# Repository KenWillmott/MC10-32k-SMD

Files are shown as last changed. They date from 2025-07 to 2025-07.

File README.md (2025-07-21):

MC10-32k-SMD

For more details, consult the wiki: https://github.com/KenWillmott/MC10-32k-SMD/wiki

A 32k memory upgrade PCB for the Radio Shack MC-10 microcomputer. It replaces the two 2kb RAM chips and the bodged 74LS32 in the MC-10. The minimal install gives you contiguous memory from 0x0000 to 0x7FFF (except for the CPU registers in low memory). So stock Micro Color Basic recognizes and uses the the upper 16k of that, and the lower half is available for general or machine language use. There are two options:
1. Page select inputs: board inputs L0 and L1 can be connected to any digital outputs, then they will select one of four video page addresses as follows:
   mc10-modes-latch
2. Battery backup: when U4 DS1210 is installed, and 3.0V is provided at the EXT BATT terminals, the memory becomes non-volatile (contents remain while main power is removed)

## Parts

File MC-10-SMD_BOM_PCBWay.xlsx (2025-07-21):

 |  |  | xxxx xxxx xxxxx xxPCS BOM (Sample Bill of Materials)
Item # | *Designator | *Qty | Manufacturer | *Mfg Part # | Description / Value | *Package/Footprint | Type | Your Instructions / Notes
1 | U2 | 1 |  | 74HCT157 | SOP-16_3.9x9.9mm_P1.27mm | SOP-16_3.9x9.9mm_P1.27mm | SMD
2 | JP2,JP1 | 2 |  |  | SolderJumper-2_P1.3mm_Open_RoundedPad1.0x1.5mm | SolderJumper-2_P1.3mm_Open_RoundedPad1.0x1.5mm | DNS | [DNP不要贴];
3 | J4,J3 | 2 |  |  | PinHeader_1x12_P2.54mm_Vertical | PinHeader_1x12_P2.54mm_Vertical | SMD | [DNP不要贴];
4 | U3 | 1 |  | KM62256CLP | SOP-28_8.4x18.16mm_P1.27mm | SOP-28_8.4x18.16mm_P1.27mm | SMD
5 | C4,C3,C1,C2 | 4 |  | CC0603KRX7R6BB104 | 100n | C_0603_1608Metric | SMD
6 | J1 | 1 |  |  | PinHeader_1x09_P2.54mm_Vertical | PinHeader_1x09_P2.54mm_Vertical | SMD | [DNP不要贴];
7 | U4 | 1 |  | DS1210S-ND | SOIC-16W_7.5x10.3mm_P1.27mm | SOIC-16W_7.5x10.3mm_P1.27mm | SMD
8 | R2,R1 | 2 |  | RC0603FR-0710KL | 10k | R_0603_1608Metric | SMD
9 | J5 | 1 |  | Conn_01x02_Pin | PinHeader_1x02_P2.54mm_Vertical | PinHeader_1x02_P2.54mm_Vertical | SMD | [DNP不要贴];
10 | BT1 | 1 |  | BatteryHolder_Keystone_500 | BatteryHolder_Keystone_500 | BatteryHolder_Keystone_500 | DNS
11 | U1 | 1 |  | 74HCT00 | SO-14_3.9x8.65mm_P1.27mm | SO-14_3.9x8.65mm_P1.27mm | SMD
Need a quick and accurante quote? Need an efficient production? Please read SMT Ordering Necessary Files & Info in 1 minute. Thank you very much! (https://www.pcbway.com/smt_ordering_guide.html)
Click for Instructions on How to Create a BOM (https://www.pcbway.com/blog/PCB_Assembly/How_to_Build_a_BOM__Bill_Of_Materials_.html)

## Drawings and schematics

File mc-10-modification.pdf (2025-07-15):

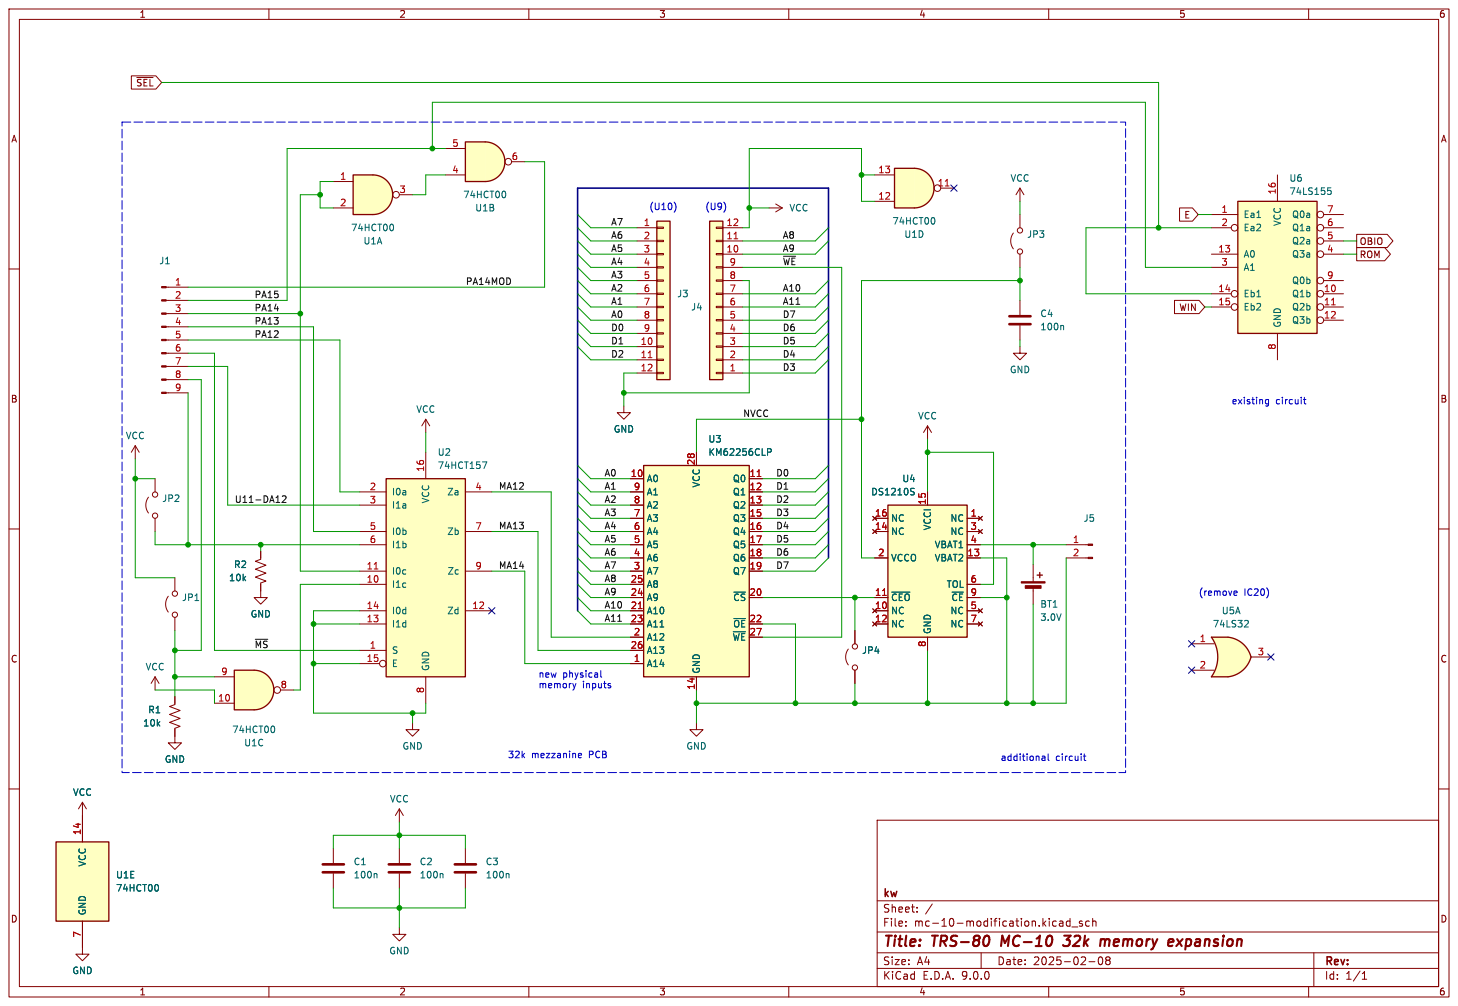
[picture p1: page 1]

8 NC 16 NC 14 VCCO 2 ~{CEO} 11 NC 10 NC 12 U4 DS1210S C2

8 NC 16 NC 14 VCCO 2 ~{CEO} 11 NC 10 NC 12

File: mc-10-modification.kicad_sch Sheet: / kw

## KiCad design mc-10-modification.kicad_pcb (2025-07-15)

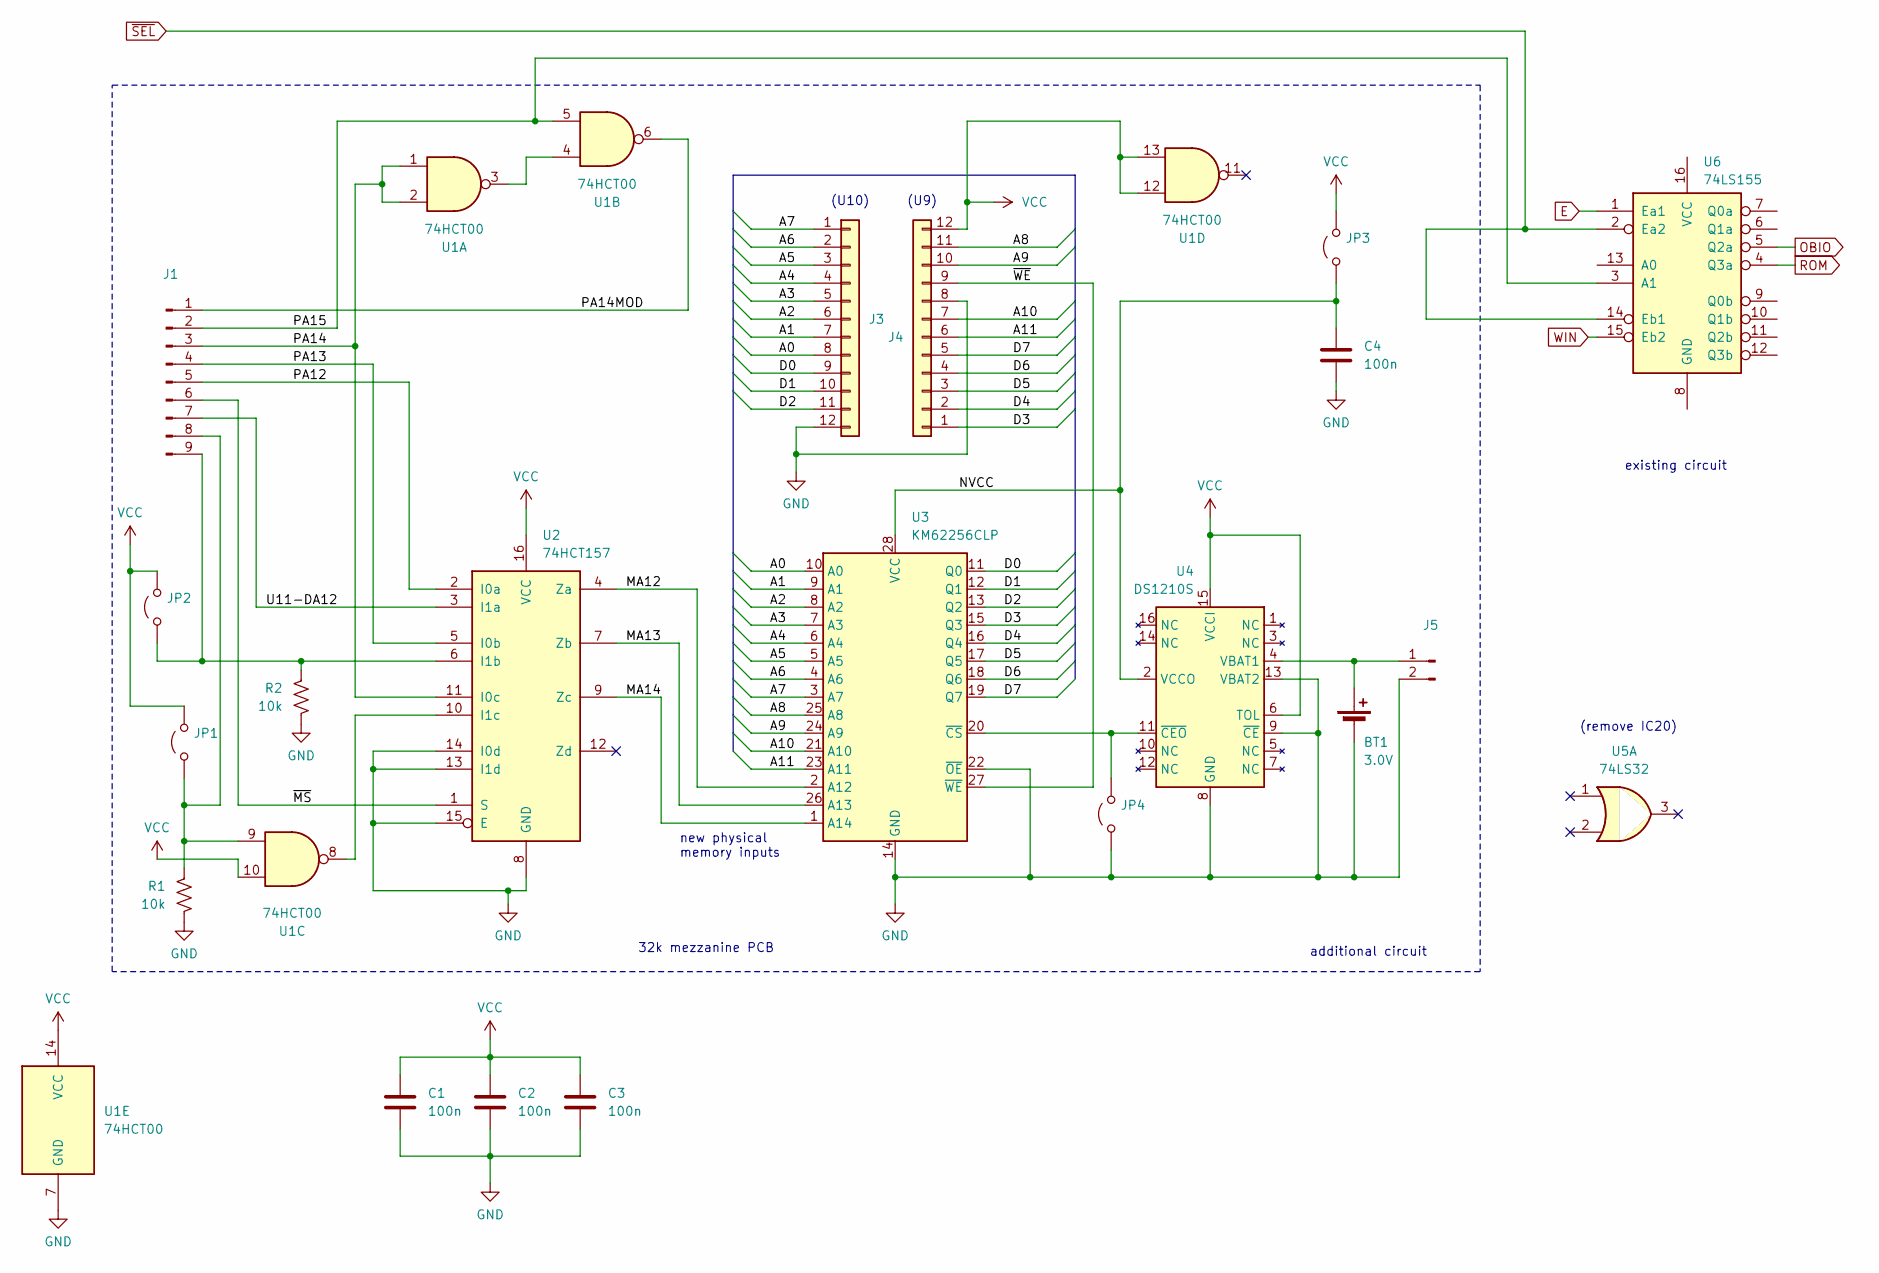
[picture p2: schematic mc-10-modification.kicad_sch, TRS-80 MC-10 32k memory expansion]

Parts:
BT1: 3.0V; BatteryHolder_Keystone_500
C1, C2, C3, C4: 100n; C_0603_1608Metric
J1: Conn_01x09_Pin; PinHeader_1x09_P2.54mm_Vertical
J3, J4: Conn_01x12; PinHeader_1x12_P2.54mm_Vertical
J5: Conn_01x02_Pin; PinHeader_1x02_P2.54mm_Vertical
JP1, JP2, JP3, JP4: Jumper_2_Open; SolderJumper-2_P1.3mm_Open_RoundedPad1.0x1.5mm
R1, R2: 10k; R_0603_1608Metric
U1: 74HCT00; SO-14_3.9x8.65mm_P1.27mm
U2: 74HCT157; SOP-16_3.9x9.9mm_P1.27mm
U3: KM62256CLP; SOP-28_8.4x18.16mm_P1.27mm
U4: DS1210S; SOIC-16W_7.5x10.3mm_P1.27mm
U5: 74LS32
U6: 74LS155

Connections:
/A0: J3.8, U3.10 (A0)
/A1: J3.7, U3.9 (A1)
/A2: J3.6, U3.8 (A2)
/A3: J3.5, U3.7 (A3)
/A4: J3.4, U3.6 (A4)
/A5: J3.3, U3.5 (A5)
/A6: J3.2, U3.4 (A6)
/A7: J3.1, U3.3 (A7)
/A8: J4.11, U3.25 (A8)
/A9: J4.10, U3.24 (A9)
/A10: J4.7, U3.21 (A10)
/A11: J4.6, U3.23 (A11)
/D0: J3.9, U3.11 (Q0)
/D1: J3.10, U3.12 (Q1)
/D2: J3.11, U3.13 (Q2)
/D3: J4.1, U3.15 (Q3)
/D4: J4.2, U3.16 (Q4)
/D5: J4.3, U3.17 (Q5)
/D6: J4.4, U3.18 (Q6)
/D7: J4.5, U3.19 (Q7)
/MA12: U2.4 (Za), U3.2 (A12)
/MA13: U2.7 (Zb), U3.26 (A13)
/MA14: U2.9 (Zc), U3.1 (A14)
/NVCC: C4.1, JP3.1 (A), U3.28 (VCC), U4.2 (VCCO)
/PA12: J1.5, U2.2 (I0a)
/PA13: J1.4, U2.5 (I0b)
/PA14: J1.3, U1.1, U1.2, U2.11 (I0c)
/PA14MOD: J1.1, U1.6
/PA15: J1.2, U1.5, U6.3 (A1)
/U11-DA12: J1.7, U2.3 (I1a)
/~MS: J1.6, U2.1 (S)
/~WE: J4.9, U3.27 (~WE)
GND: BT1.2 (-), C1.2, C2.2, C3.2, C4.2, J3.12, J4.8, J5.2, JP4.1 (A), R1.2, R2.2, U1.7 (GND), U2.8 (GND), U2.13 (I1d), U2.14 (I0d), U2.15 (E), U3.14 (GND), U3.22 (~OE), U4.8 (GND), U4.9 (~CE), U4.13 (VBAT2)
unnamed: BT1.1 (+), J5.1, U4.4 (VBAT1)
unnamed: J1.8, JP1.1 (A), R1.1, U1.9
unnamed: J1.9, JP2.1 (A), R2.1, U2.6 (I1b)
unnamed: JP4.2 (B), U3.20 (~CS), U4.11 (~CEO)
unnamed: U1.3, U1.4
unnamed: U1.8, U2.10 (I1c)
unnamed: U6.2 (Ea2), U6.14 (Eb1)
VCC: C1.1, C2.1, C3.1, J4.12, JP1.2 (B), JP2.2 (B), JP3.2 (B), U1.10, U1.12, U1.13, U1.14 (VCC), U2.16 (VCC), U4.6 (TOL), U4.15 (VCCI)

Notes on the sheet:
32k mezzanine PCB
(remove IC20)
(U9)
additional circuit
(U10)
existing circuit
new physical memory inputs

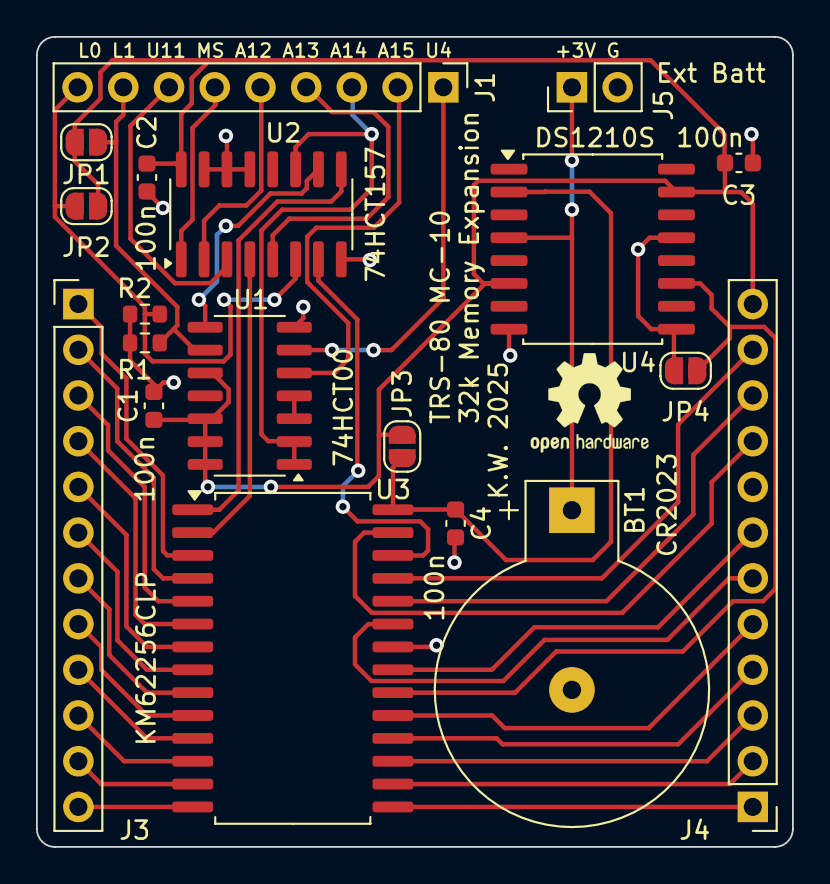
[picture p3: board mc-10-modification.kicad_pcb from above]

Board: 2 copper layers, 42.0 x 45.0 mm, 19 parts (0 on the bottom side), 40 nets.
